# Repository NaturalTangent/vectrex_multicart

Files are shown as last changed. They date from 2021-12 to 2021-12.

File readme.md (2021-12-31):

# Vectrex Multicart

This is a PCB for a simple vectrex multicart. Games are selected using DIP switches on the cart (power-off first).

The PCB was developed using kicad (not sure which version, it was a few years ago...). I've just re-discovered it on my hard disk and converted to kicad 6.0.0.

## Schematic

I think the original schematic came from https://harmlesslion.com/text/vectrex_multicart.htm

schematic

## PCB

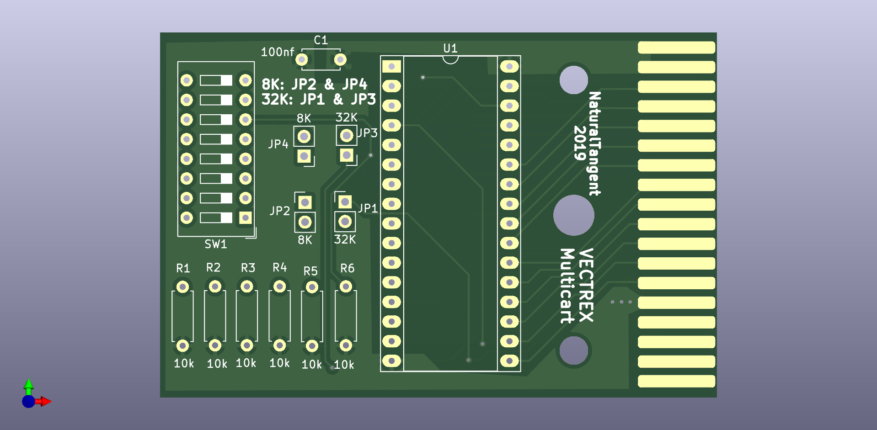
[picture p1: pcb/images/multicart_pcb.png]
PCB


## Cart EPROM

_make8k_ is a quick and dirty tool for concatenating multiple game ROMs into a single binary that can be written to the cart.

The resulting binary must be written to the EPROM using an EPROM burner (e.g. TL866).

### make8k

To build you will need a C++ compiler. On linux it can be built as follows;

```shell
gcc ./make8k.cpp -o make8k
```

Using it to generate the EPROM binary requires a set of vectrex ROMs (you'll need to find these elsewhere) and a simple configuration file.

The configuration file is a list of the ROM file names, one per line for each of the ROMs to be added to the EPROM. E.g.

```
ARMOR.bin
BEDLAM.bin
BERZERK.bin
BLITZ.bin
CASTLE.bin
CHASM.bin
CRAZY.bin
DUALVEC2.bin
HEADSUP.bin
HYPER.bin
LANDER.bin
MELODY.bin
MINE3.bin
NARROW.bin
NARZOD.bin
PATRIOT.bin
POLAR.bin
POLE.bin
RIPOFF.bin
SCRAMBLE.bin
SOLAR.bin
SPACE.bin
SPIKE.bin
SPINBALL.bin
STARHAWK.bin
STARTREK.bin
SWEEP.bin
WEBWARS.bin
```

Copy the ROM files, the config file, and the make8k executable into the same folder and then generate the EPROM binary by executing the following;

```shell
make8k config.txt eprom.bin
```

This will generate a file named _eprom.bin_ that can now be written to your EPROM (using an EPROM burner such as a TL866).

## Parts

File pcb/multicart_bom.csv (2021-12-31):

Id | Designator | Package | Quantity | Designation | Supplier and ref
1 | U1 | DIP-32_W15.24mm_Socket_LongPads | 1 | SST39SF020
2 | SW1 | SW_DIP_SPSTx08_Slide_9.78x22.5mm_W7.62mm_P2.54mm | 1 | Select
3 | R5,R2,R3,R1,R4,R6 | R_Axial_DIN0207_L6.3mm_D2.5mm_P7.62mm_Horizontal | 6 | 10k
4 | J1 | VECTREX_CART | 1 | Vectrex Cartridge Connector
5 | C1 | C_Disc_D4.7mm_W2.5mm_P5.00mm | 1 | 100nf
6 | H2 | MountingHole_5.3mm_M5 | 1 | MountingHoleCentre
7 | H1,H3 | MountingHole_3.7mm | 2 | MountingHole
8 | JP1,JP3 | PinHeader_1x02_P2.54mm_Vertical | 2 | 32K
9 | JP2,JP4 | PinHeader_1x02_P2.54mm_Vertical | 2 | 8K

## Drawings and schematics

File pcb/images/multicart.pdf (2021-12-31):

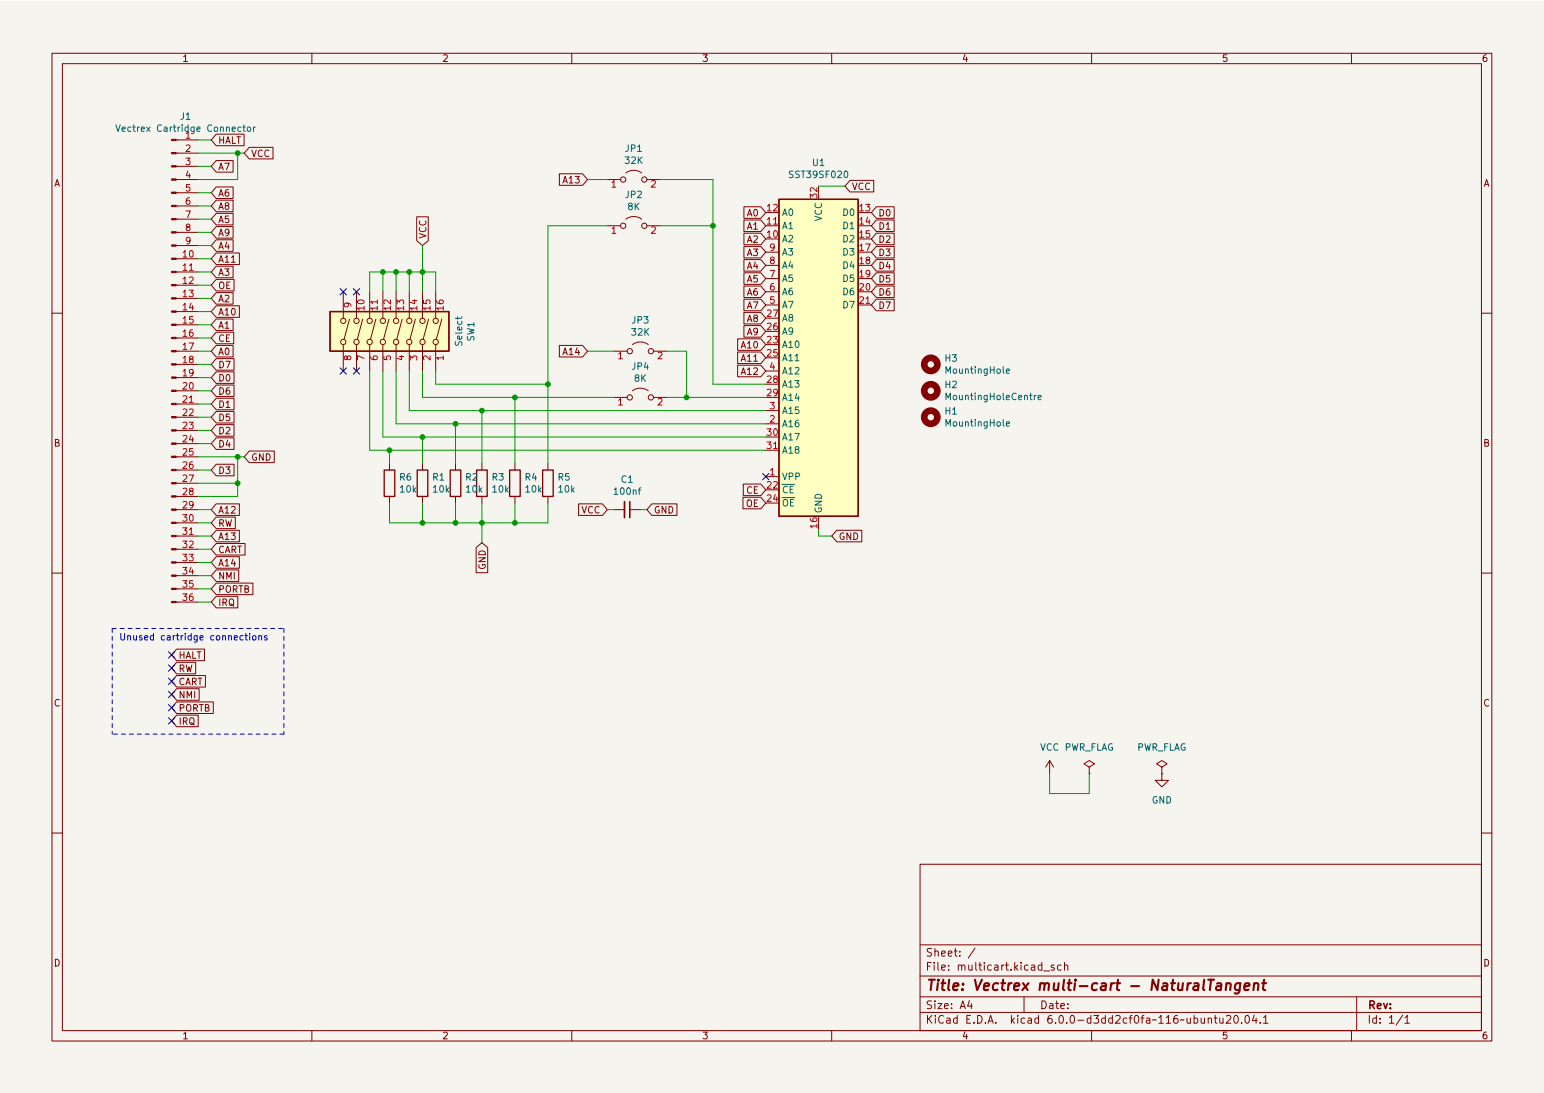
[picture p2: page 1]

File: multicart.kicad_sch Sheet: /
Id: 1/1 Title: Vectrex multi-cart - NaturalTangent

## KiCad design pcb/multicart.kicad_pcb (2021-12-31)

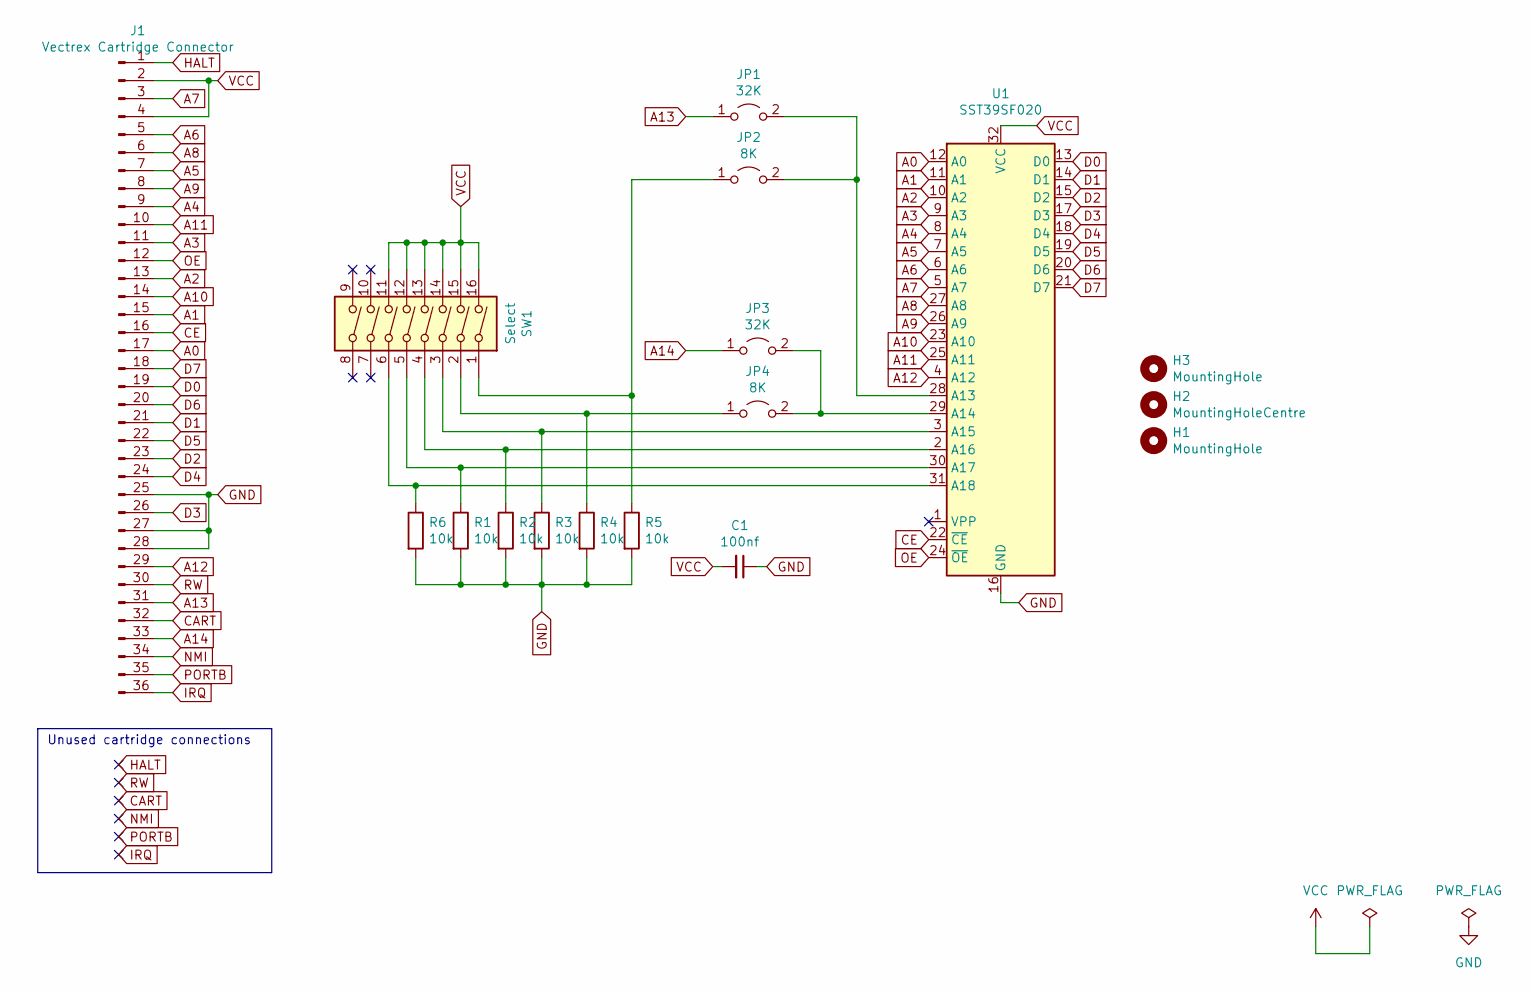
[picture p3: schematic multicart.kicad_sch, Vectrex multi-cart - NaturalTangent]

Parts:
C1: 100nf; C_Disc_D4.7mm_W2.5mm_P5.00mm
H1, H3: MountingHole; MountingHole_3.7mm
H2: MountingHoleCentre; MountingHole_5.3mm_M5
J1: Vectrex Cartridge Connector; VECTREX_CART
JP1, JP3: 32K; PinHeader_1x02_P2.54mm_Vertical
JP2, JP4: 8K; PinHeader_1x02_P2.54mm_Vertical
R1, R2, R3, R4, R5, R6: 10k; R_Axial_DIN0207_L6.3mm_D2.5mm_P7.62mm_Horizontal
SW1: Select; SW_DIP_SPSTx08_Slide_9.78x22.5mm_W7.62mm_P2.54mm
U1: SST39SF020; DIP-32_W15.24mm_Socket_LongPads

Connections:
A0: J1.17, U1.12 (A0)
A1: J1.15, U1.11 (A1)
A2: J1.13, U1.10 (A2)
A3: J1.11, U1.9 (A3)
A4: J1.9, U1.8 (A4)
A5: J1.7, U1.7 (A5)
A6: J1.5, U1.6 (A6)
A7: J1.3, U1.5 (A7)
A8: J1.6, U1.27 (A8)
A9: J1.8, U1.26 (A9)
A10: J1.14, U1.23 (A10)
A11: J1.10, U1.25 (A11)
A12: J1.29, U1.4 (A12)
A13: J1.31, JP1.1 (A)
A14: J1.33, JP3.1 (A)
CART: J1.32
CE: J1.16, U1.22 (~CE)
D0: J1.19, U1.13 (D0)
D1: J1.21, U1.14 (D1)
D2: J1.23, U1.15 (D2)
D3: J1.26, U1.17 (D3)
D4: J1.24, U1.18 (D4)
D5: J1.22, U1.19 (D5)
D6: J1.20, U1.20 (D6)
D7: J1.18, U1.21 (D7)
GND: C1.1, J1.25, J1.27, J1.28, R1.2, R2.2, R3.2, R4.2, R5.2, R6.2, U1.16 (GND)
HALT: J1.1
IRQ: J1.36
NMI: J1.34
unnamed: JP1.2 (B), JP2.2 (B), U1.28 (A13)
unnamed: JP2.1 (A), R5.1, SW1.1
unnamed: JP3.2 (B), JP4.2 (B), U1.29 (A14)
unnamed: JP4.1 (A), R4.1, SW1.2
unnamed: R1.1, SW1.5, U1.30 (A17)
unnamed: R2.1, SW1.4, U1.2 (A16)
unnamed: R3.1, SW1.3, U1.3 (A15)
unnamed: R6.1, SW1.6, U1.31 (A18)
OE: J1.12, U1.24 (~OE)
PORTB: J1.35
RW: J1.30
VCC: C1.2, J1.2, J1.4, SW1.11, SW1.12, SW1.13, SW1.14, SW1.15, SW1.16, U1.32 (VCC)

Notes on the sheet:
Unused cartridge connections

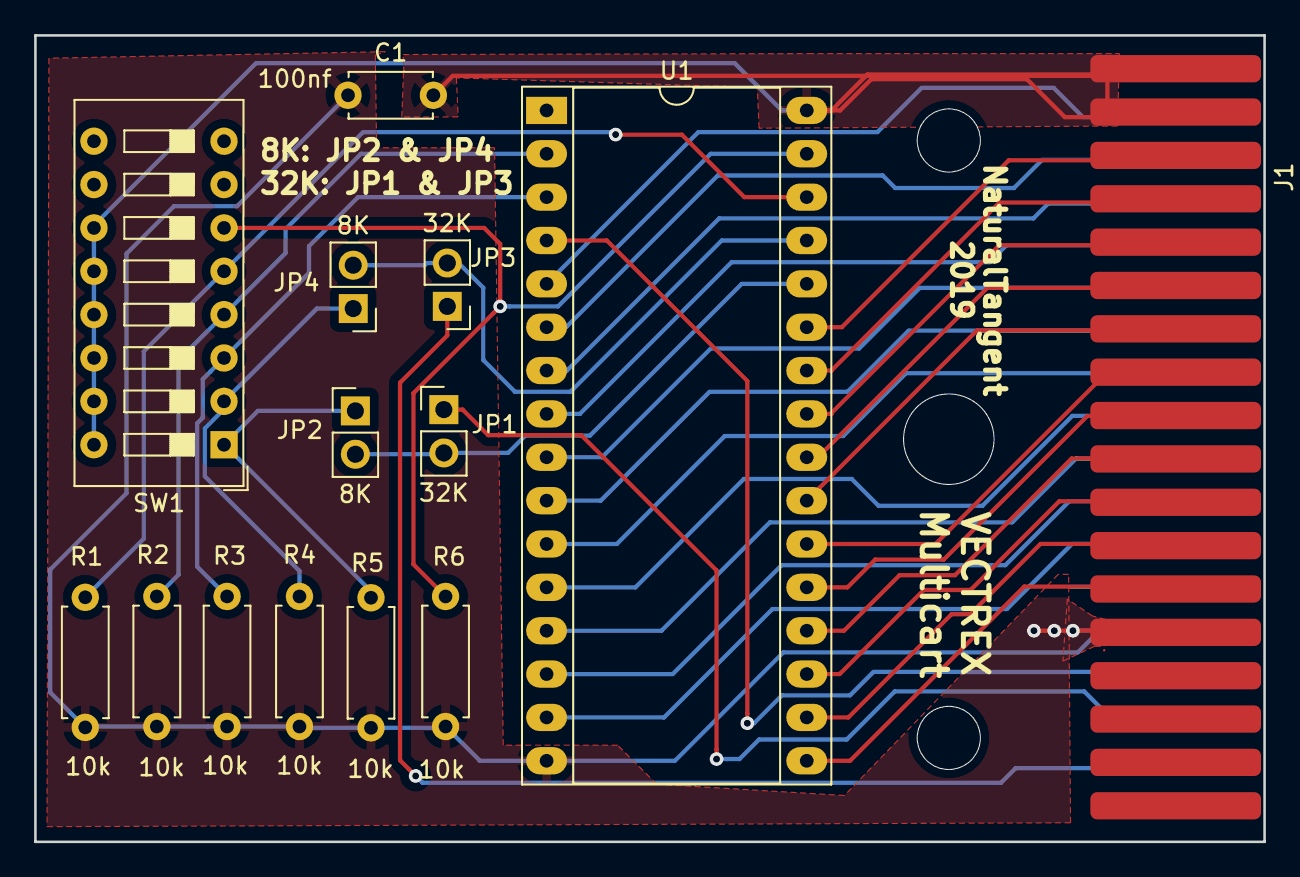
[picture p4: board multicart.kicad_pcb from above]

Board: 2 copper layers, 72.0 x 47.2 mm, 17 parts (0 on the bottom side), 35 nets.

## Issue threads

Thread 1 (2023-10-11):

Question

OK1FSX, 2023-10-11:
Hello dear NaturalTangent, thanks for your multicart design. This is not an issue, I only would like to ask. What do you think how critical is the material of connector surface GOLD/TIN and also the connecting of memory chip SOLDERED/SOCKET?? I can not make my multicart work and I am looking for the reason. I have PCB from JLCPCB with tin surface and chip is placed in socket. Maybe this is the reason. What are your experiences? Thank you very much for reading, any advice would be appreciated. Thanks and regards, Tomas Kozeluh

NaturalTangent, 2023-10-11:
Hi Tomas. I didn't specify any special material when I had them fabricated - I went for the cheapest option. I guess it depends on how often you intend to insert and remove it.

The DIP switch positions may be important depending on the size of the EPROM you have used. I used a 39SF020 that I had lying around. Since it was smaller than the max size supported I recall that I had to set some of the (upper address?) DIP switches high or low (I can't remember now).

Assuming I've left the switches in a working position since the last time I used it, they are currently set as follows (with the 39SF020).

JP1=open
JP3=open
JP2=closed
JP4=closed

1=off
2=off
3=on
4=on
5=off
6=off
7=off
8=on

Looking at the cart with the connector at the top and DIP switches at the bottom (off is down, but I may or may not have soldered the switch pack upside down - I can't remember).

Hopefully some of that will help!
Andy

OK1FSX, 2023-10-12:
Thank you very much Andy, I'll post a message when I find out what I'm doing wrong. Have a nice day. Tomas

OK1FSX, 2023-10-19:
Dear Andy and multicart builders, be aware small bug in the schematic. When using SST39SF020 as in the schematic described, the pin #31 is not A18 but WE# (write enable) which MUST be always in HIGH state when reading. When would #31 pin be LOW, multicart will not work. Now my multicart works fine and I am happy :-), have nice day.  Tom OK1FSX

NaturalTangent, 2023-10-22:
Glad you figured it out! :)

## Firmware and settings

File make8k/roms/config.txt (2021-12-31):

Test Rev. 4 (1982) (PD).vec
Armor Attack (1982).vec
Bedlam (1983).vec
Berzerk (1982).vec
Blitz! - Action Football (1982).vec
Clean Sweep (1982).vec
Clean Sweep (Mr Boston Version) (1982).vec
config.txt
Cosmic Chasm (1982).vec
Fortress of Narzod (1982).vec
Heads Up - Action Soccer (1983).vec
Hyperchase (1982).vec
Mine Storm (1982).vec
Mine Storm II (1983).vec
Narrow Escape (2-D Version by Fred Taft) (1983) [h1].vec
Polar Rescue (1983).vec
Pole Position (1982).vec
Rip-Off (1982).vec
Scramble (1982).vec
Solar Quest (1982).vec
Space Wars (1982).vec
Spike (1983).vec
Spinball (1983).vec
Star Castle (1983).vec
Star Hawk (1982).vec
Star Ship (1982).vec
Star Trek - The Motion Picture (1982).vec
Tour De France (1983) (Prototype).vec
Web Warp (1983).vec
